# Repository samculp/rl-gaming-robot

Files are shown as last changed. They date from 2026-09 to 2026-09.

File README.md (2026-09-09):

# RL Gaming Robot

The RL Gaming Robot is a senior design project focused on developing a Reinforcement Learning system that learns to play games through repeated attempts and applies its learned behavior to a game to ultimately improve its score.

The current target game is Tetris. The long-term goal is for the RL agent to make gameplay decisions and output controller commands that are translated into physical actions pressed on a controller by a robotic system.

This repository contains the software and hardware elements used to create the project.

## Repository Structure

```text
RL-Gaming-Robot/

├── hardware/
│   ├── experiments/
│   │   ├── actuator_pulse/
│   │   └── cad_files/
│   └── production/
│
├── software/
│   ├── requirements/
│   ├── environment/
│   ├── agent/
│   └── test_cases/
│
└── README.md
```

## Hardware

The `hardware` directory contains the mechanical and electronic development files for the RL Gaming Robot.

This includes:

* Actuator experiments and testing
* CAD models and mechanical designs
* Controller mounting and interaction components
* Production hardware designs
* Hardware documentation and validation

See the [hardware README](hardware/README.md) for additional information.

## Software

The `software` directory contains the software required to develop and operate the RL system.

This includes:

* Python environment and dependency requirements
* Game environment code
* Reinforcement Learning agent code
* Software test cases

The software is responsible for interacting with the game environment, training and executing the RL agent, and producing controller actions for the hardware system.

See the [software README](software/README.md) for additional information.

## System Overview

The intended system operates as a feedback loop:

```text
┌─────────────────┐
│    NES Tetris   │
└────────┬────────┘
         │
         │ Game State
         ▼
┌─────────────────┐
│ Game Environment│
└────────┬────────┘
         │
         │ State
         ▼
┌─────────────────┐
│    RL Agent     │
└────────┬────────┘
         │
         │ Controller Action
         ▼
┌─────────────────┐
│ Robot Controller│
└────────┬────────┘
         │
         │ Physical Command
         ▼
┌─────────────────┐
│  Robotic System  │
└────────┬────────┘
         │
         │ Button Press
         ▼
┌─────────────────┐
│  NES Controller │
└────────┬────────┘
         │
         └──────────────► NES Tetris
```

The game produces a new state after each action, allowing the RL agent to continually evaluate the game and select its next action.

## Testing

Testing is an integral part of the project and is performed throughout both software and hardware development.

Software testing focuses on:

* Game-state processing
* RL agent behavior
* Action generation
* Software component integration
* Model performance and repeatability

Hardware testing focuses on:

* Actuator performance
* Button press accuracy
* Timing and reliability
* Mechanical positioning
* Hardware/software integration

Test cases are maintained within the appropriate software and hardware directories.

## Development Philosophy

The project is organized around **experimentation, validation, and integration**.

Development follows these general principles:

1. **Experiment** — Develop and test individual concepts and components.
2. **Validate** — Verify that components meet their intended requirements.
3. **Integrate** — Combine validated software and hardware components.
4. **Test** — Evaluate the complete system and identify integration issues.
5. **Iterate** — Use test results to improve the system.

Experimental implementations should be validated before being incorporated into the production system.

## Project Goals

The primary goals of the RL Gaming Robot project are to:

* Develop an RL agent capable of improving its gameplay through repeated attempts.
* Create a software environment for training and evaluating the agent.
* Develop a robotic system capable of physically interacting with a gaming controller.
* Establish reliable communication between the software and hardware systems.
* Test the performance and reliability of the complete system.
* Demonstrate the transfer of learned behavior from the software environment to physical gameplay.

## Current Development Status

The project is being developed incrementally, beginning with the software RL environment and agent before progressing toward full hardware integration.

Major development stages include:

1. Software environment development
2. RL agent development and training
3. Software testing and performance evaluation
4. Hardware development and validation
5. Software/hardware integration
6. Full-system testing
7. Final NES Tetris demonstration

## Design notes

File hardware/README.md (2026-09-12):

# Hardware

Hardware design, firmware, schematics, experiments, and documentation for the RL gaming robot.

## Directories

* [`electronics/`](electronics/) — Electrical system documentation, PCB design, power budget, and wiring diagrams.
* [`mechanical/`](mechanical/) — Mechanical design documentation and CAD files.
* [`firmware/`](firmware/) — Arduino firmware for the hardware control system.
* [`experiments/`](experiments/) — Hardware and controller experiments used during development.
* [`photos/`](photos/) — Miscellaneous ardware photos.

## System Overview

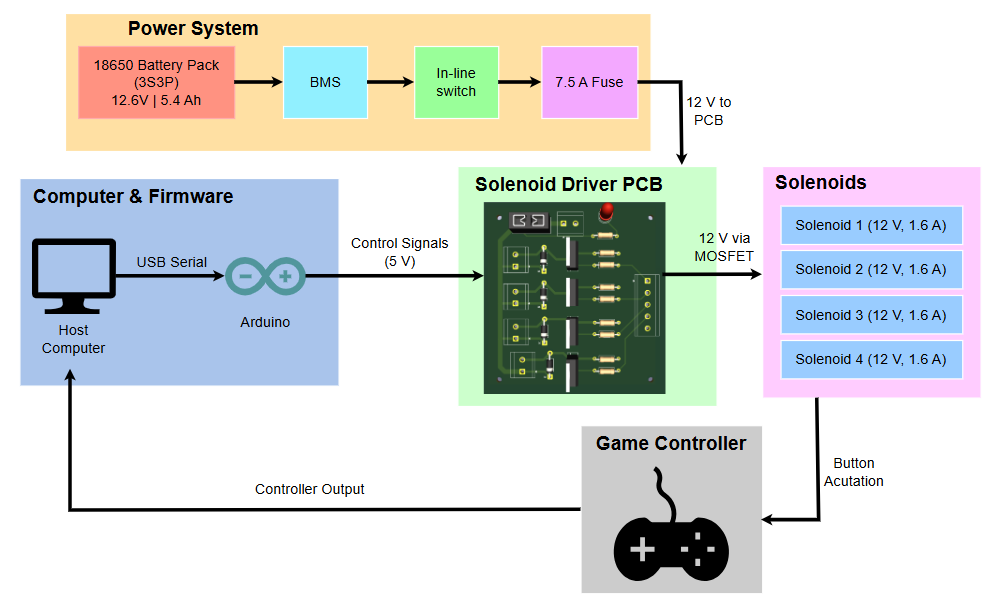
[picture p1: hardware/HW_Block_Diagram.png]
Hardware Block Diagram


For detailed electrical architecture and subsystem documentation, see [`electronics/`](electronics/).

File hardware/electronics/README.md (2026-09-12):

# Electronics

The electronics system controls and powers the solenoid actuators used to physically operate the game controller.

## Subsystems

- [PCB](pcb/README.md) — Solenoid driver PCB design and fabrication files
- [Power](power/power_budget.md) — Battery and system power requirements
- [Wiring](wiring/) — Electrical wiring and connections (visual)

## Signal Path

Arduino → MOSFET driver → Solenoids

## Power Path

Battery → BMS → Power switch → Fuse  → Solenoid driver PCB → Solenoids

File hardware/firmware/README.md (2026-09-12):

# Firmware

Arduino firmware for controlling the solenoid driver PCB and translating commands received over USB into physical controller inputs.

## Planned Contents

- Arduino source code
- Pin assignments
- Serial communication protocol
- Solenoid control logic

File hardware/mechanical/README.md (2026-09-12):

# Mechanical

Mechanical components for mounting and positioning the solenoid actuators over the game controller.

## CAD Files

- `Actuator Plate.f3d` — Mounting plate for the solenoid actuators; actuators are friction fit into sleeves
- `SNES Cradle.f3d` — Mount for the game controller
- `Solenoid Sleeve.f3d` — Test sleeve for positioning and guiding the solenoid
- `snes_overlay.jpg` — Controller reference image used during CAD design

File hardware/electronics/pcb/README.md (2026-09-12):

# Solenoid Driver PCB

Custom PCB for interfacing the Arduino with four 12 V solenoid actuators.

## Components

| Component | Quantity | Purpose |
| --- | ---: | --- |
| IRLZ44N N-channel MOSFET | 4 | Electrically switches each solenoid on and off using the Arduino control signal. |
| 1N4004 diode | 4 | Provides flyback protection by suppressing the voltage spike generated when a solenoid is switched off. |
| 220 Ω gate resistor | 4 | Limits current into each MOSFET gate and provides controlled gate drive. |
| 10 kΩ pull-down resistor | 4 | Pulls the gate of each MOSFET down to GND when it is not being driven HIGH by the Arduino. |
| Green LED | 1 | Indicates that the PCB is receiving power. |
| 1 kΩ resistor | 1 | Limits current through the power indicator LED. |
| 2-position screw terminal | 1 | Provides the 12 V power input connection. |
| 2-position screw terminal | 4 | Provides connections for the four solenoids and power/ground distribution. |
| 5-position screw terminal | 1 | Provides the control signal and ground connections between the Arduino and PCB. |
| 7.5 A blade fuse | 1 | Protects the PCB and solenoid power circuit from excessive current. |
| Fuse holder | 1 | Holds the 7.5 A blade fuse in the solenoid power path. |
| M2 mounting holes | 4 | Secure the PCB to the mechanical assembly. |

## Files

* `solenoid_driver.kicad_sch` — Electrical schematic.
* `solenoid_driver.kicad_pcb` — PCB layout.
* `solenoid_driver.kicad_pro` — KiCad project file.

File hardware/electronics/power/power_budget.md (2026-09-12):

# Power Budget

## Battery Pack

The battery pack consists of nine 18650 lithium-ion cells configured as 3S3P. Each cell has an approximate capacity of 1.8 Ah and a nominal voltage of 3.6-3.7 (4.2 V fully charged).

- Configuration: 3S3P
- Cells: 9 × 18650
- Nominal voltage: 10.8-11.1 V
- Maximum voltage: 12.6 V
- Capacity: 5.4 Ah
- Approximate energy: 58-60 Wh

## Power Path

Battery → BMS → In-line switch → XT60 → 7.5 A fuse → PCB → Solenoids

The Arduino is powered separately through USB.

## Solenoid Load

Each solenoid is rated for 12 V and draws a maximum of 1.6 A.

| Load | Voltage | Max Current | Quantity | Total Max Current |
|---|---:|---:|---:|---:|
| Solenoid | 12 V | 1.6 A | 4 | 6.4 A |

The maximum combined solenoid current is approximately 6.4 A when all four solenoids are activated simultaneously.

## Protection

- Fuse: 7.5 A blade fuse
- Maximum solenoid load: 6.4 A
- Fuse margin: 1.1 A

The BMS (battery management system) provides:
- Overcharge protection
- Over-discharge protection
- Overcurrent and short-circuit protection
- Cell balancing

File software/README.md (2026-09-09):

# RL Gaming Robot Software
This directory contains the software development files for the RL Gaming Robot project. It includes requirements, environment python codes, agent python codes, and test case codes.

## Directory Structure
```text

software/
├── requirements/
├── environment/
├── agent/
└── test_cases/

```

## Requirements
The requirements for the software side of the project must include a few main features
* Python 3.x - Main programming language
    * Gymnasium Library - Reinforcement Learning environment
    * PyTorch - Used to develop and train the RL model 
    * PyToch Vision - Addon to PuTorch to handle video and images
    * PyInput - Used to listen to inputs while not having an open window like PyGame
* Git - Version control and repository management

## Environment
This project plans to use the gymnasium library to create an environment for the agent

## Agent
The agent is also provided via Gymnasium

## Test Cases
Test cases are recorded and graphed/stored, showing that the RL model is improving.

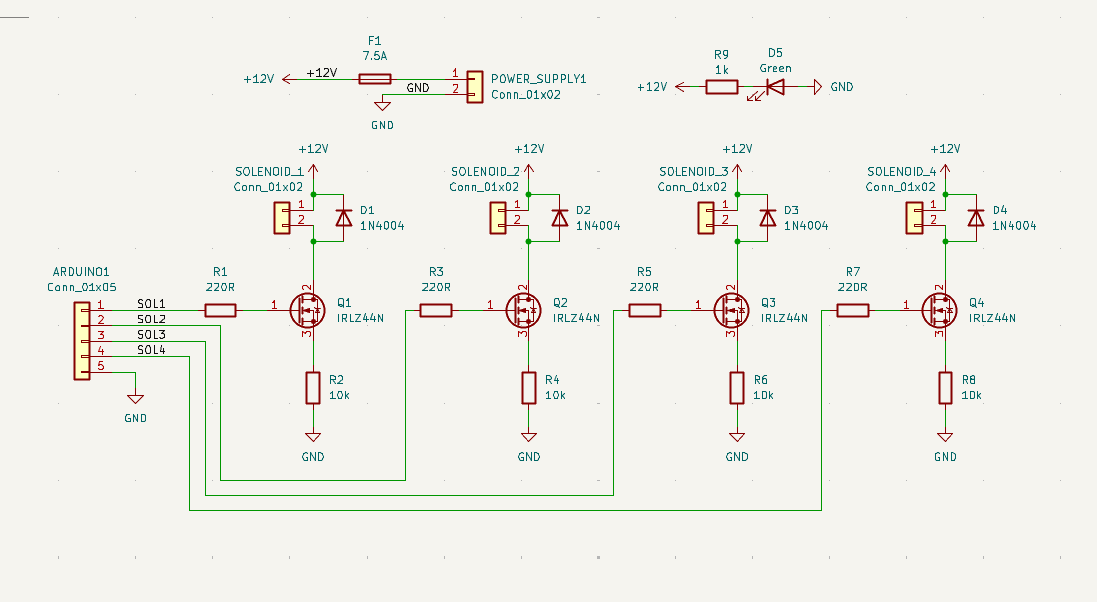
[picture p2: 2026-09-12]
hardware/electronics/wiring/schematic_diagram.png

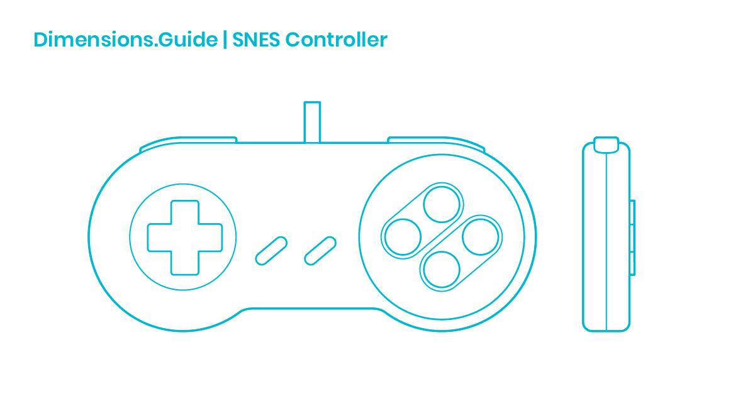
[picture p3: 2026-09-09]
hardware/mechanical/cad/snes_overlay.jpg

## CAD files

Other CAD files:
hardware/mechanical/cad/Actuator Plate.f3d
hardware/mechanical/cad/SNES Cradle.f3d
hardware/mechanical/cad/Solenoid Sleeve.f3d

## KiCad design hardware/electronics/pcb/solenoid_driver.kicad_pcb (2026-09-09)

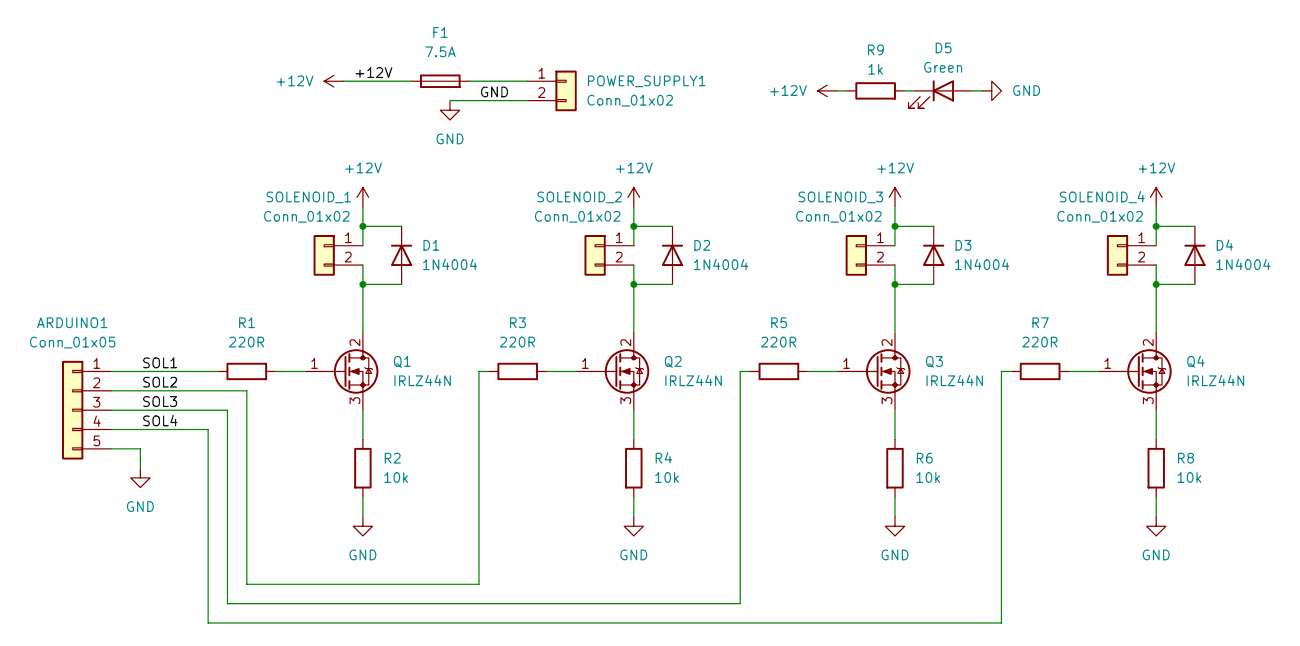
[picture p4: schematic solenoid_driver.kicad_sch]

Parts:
ARDUINO1: Conn_01x05; TerminalBlock_CUI_TB007-508-05_1x05_P5.08mm_Horizontal
D1, D2, D3, D4: 1N4004; D_DO-41_SOD81_P10.16mm_Horizontal
D5: Green; LED_D5.0mm
F1: 7.5A; Fuseholder_Blade_Mini_Keystone_3568
POWER_SUPPLY1: Conn_01x02; TerminalBlock_CUI_TB007-508-02_1x02_P5.08mm_Horizontal
Q1, Q2, Q3, Q4: IRLZ44N; TO-220-3_Vertical
R1, R3, R5, R7: 220R; R_Axial_DIN0207_L6.3mm_D2.5mm_P10.16mm_Horizontal
R2, R4, R6, R8: 10k; R_Axial_DIN0207_L6.3mm_D2.5mm_P10.16mm_Horizontal
R9: 1k; R_Axial_DIN0207_L6.3mm_D2.5mm_P10.16mm_Horizontal
SOLENOID_1, SOLENOID_2, SOLENOID_3, SOLENOID_4: Conn_01x02; TerminalBlock_CUI_TB007-508-02_1x02_P5.08mm_Horizontal

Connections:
+12V: D1.1 (K), D2.1 (K), D3.1 (K), D4.1 (K), F1.1, R9.1, SOLENOID_1.1, SOLENOID_2.1, SOLENOID_3.1, SOLENOID_4.1
/SOL1: ARDUINO1.1, R1.1
/SOL2: ARDUINO1.2, R3.1
/SOL3: ARDUINO1.3, R5.1
/SOL4: ARDUINO1.4, R7.1
GND: ARDUINO1.5, D5.2 (A), POWER_SUPPLY1.2, R2.2, R4.2, R6.2, R8.2
unnamed: D1.2 (A), Q1.2 (D), SOLENOID_1.2
unnamed: D2.2 (A), Q2.2 (D), SOLENOID_2.2
unnamed: D3.2 (A), Q3.2 (D), SOLENOID_3.2
unnamed: D4.2 (A), Q4.2 (D), SOLENOID_4.2
unnamed: D5.1 (K), R9.2
unnamed: F1.2, POWER_SUPPLY1.1
unnamed: Q1.1 (G), R1.2
unnamed: Q1.3 (S), R2.1
unnamed: Q2.1 (G), R3.2
unnamed: Q2.3 (S), R4.1
unnamed: Q3.1 (G), R5.2
unnamed: Q3.3 (S), R6.1
unnamed: Q4.1 (G), R7.2
unnamed: Q4.3 (S), R8.1

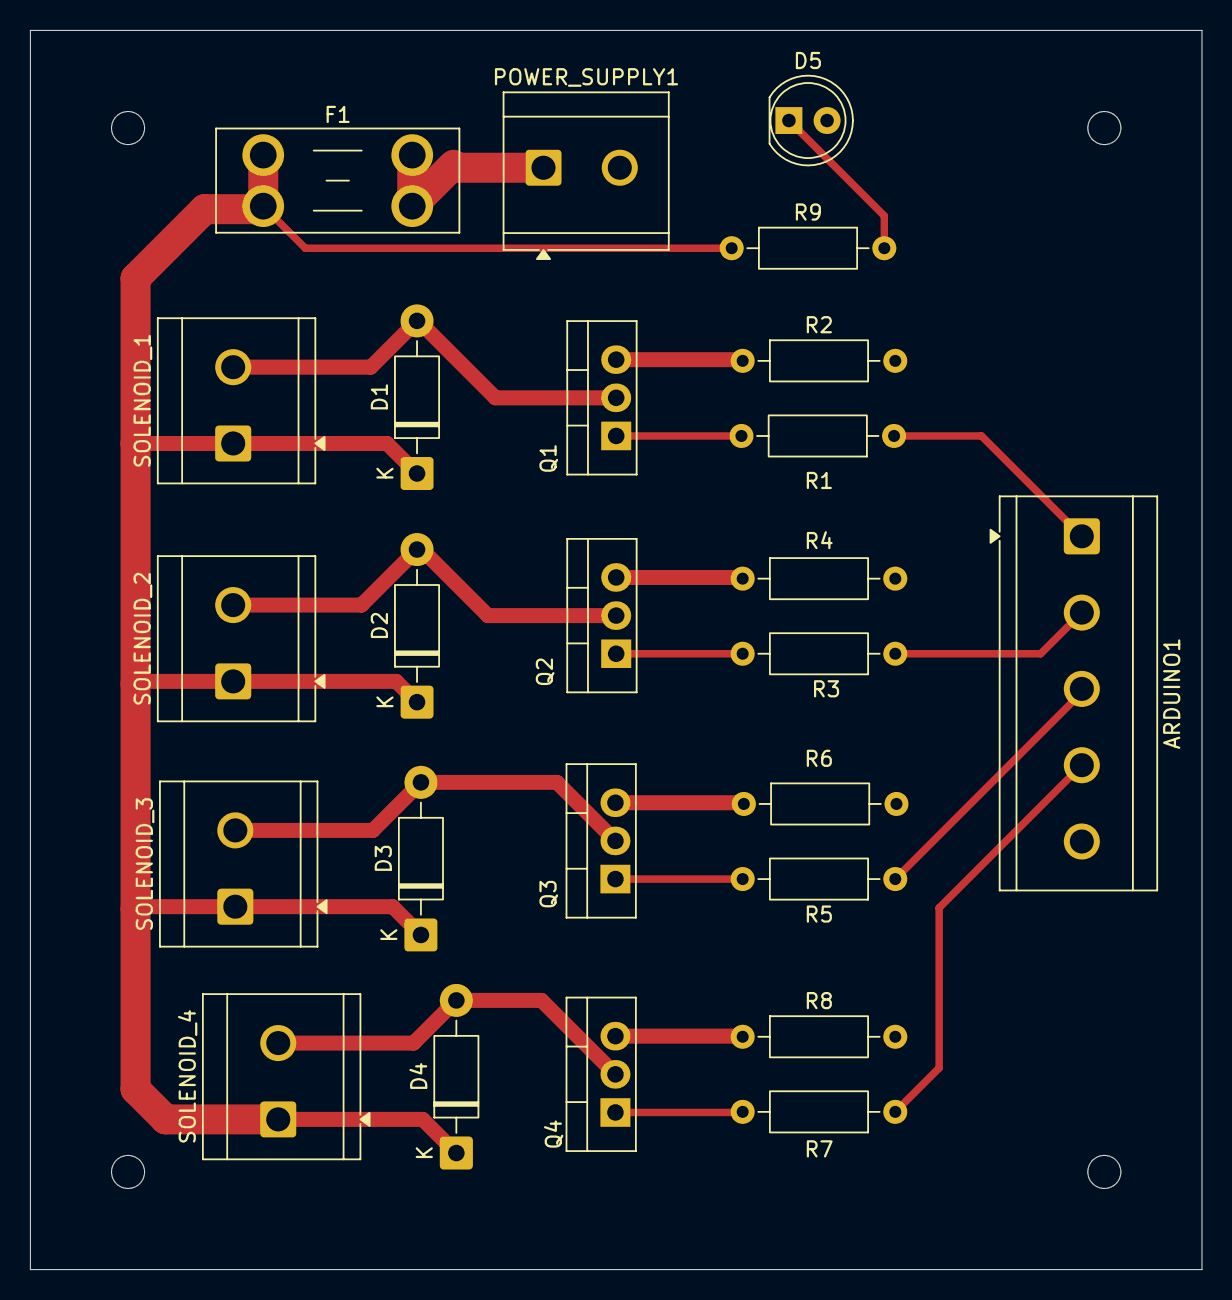
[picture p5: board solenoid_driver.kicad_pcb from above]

Board: 2 copper layers, 78.0 x 82.5 mm, 25 parts (0 on the bottom side), 20 nets.

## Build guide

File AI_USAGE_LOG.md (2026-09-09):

# AI Usage & Verification Log

**Project Name:** RL Gaming Robot

---

## Overview & AI Usage Statement

### Overview & AI Usage Statement

AI tools were used throughout the project as a supplemental development resource for brainstorming, troubleshooting, and improving implementation approaches. AI-generated code and recommendations were reviewed, tested, and modified by the project team before being incorporated into the project. The team remains responsible for understanding and verifying all implemented solutions. AI was not treated as a replacement for independent research, engineering judgment, or testing.

### Responsible AI Usage

AI was used responsibly by treating its output as a starting point rather than an authoritative source. Generated code was reviewed for correctness, tested in the project environment, and modified when necessary. Project decisions and final implementations were verified by the team, and AI assistance was documented in this log to maintain transparency and accountability.

---

## Entry 1: Prototype 1 - SNES USB Controller Input Mapping Experiment

* **Date:** August 31, 2026  
* **Tool Used:** ChatGPT  
* **Associated Git Issue:** Test SNES USB controller input mapping  
* **Associated Feature Branch:** `controller-input-test`  

### Exact Prompt Submitted:

> "quick python script for testing input on this snes usb controller i just got from walmart"

### AI Output Summary & Code Generated

AI generated a Python script using the `pygame` library to:

* Detect connected USB controllers.
* Display the controller name.
* Display the number of buttons, axes, and hats detected.
* Print button press events.
* Print button release events.
* Print joystick axis movement values.
* Print D-pad or hat movement values when applicable.

The generated experiment allowed the physical SNES USB controller to be tested interactively.

### Human Testing, Verification & Results

The controller was manually tested using the generated Python experiment. The following input mappings were observed and recorded:

#### Button Mapping

| SNES Button | Input Mapping |
|---|---:|
| X | Button 0 |
| A | Button 1 |
| B | Button 2 |
| Y | Button 3 |
| Select | Button 8 |
| Start | Button 9 |

#### D-Pad Mapping

The controller D-pad was detected as two joystick axes rather than individual buttons or a joystick hat.

| Direction | Axis | Value When Pressed |
|---|---:|---:|
| Left | Axis 0 | -1 |
| Right | Axis 0 | 1 |
| Up | Axis 1 | -1 |
| Down | Axis 1 | 1 |
| Released | Axis 0 / Axis 1 | Approximately -0.01 |

### Human Review & Modifications Identified

Testing identified that the D-pad does not return exactly `0` when released. Instead, the controller reports a value of approximately `-0.01`.

Based on this result, future controller input handling should implement a dead zone rather than checking for an exact axis value of zero.

Example dead zone approach:

```python
DEADZONE = 0.5

if axis_0 < -DEADZONE:
    print("LEFT")
elif axis_0 > DEADZONE:
    print("RIGHT")

if axis_1 < -DEADZONE:
    print("UP")
elif axis_1 > DEADZONE:
    print("DOWN")
```

---

## Entry 2: CI/CD Infrastructure - Pytest Unit Test Setup

* **Date:** September 8, 2026  
* **Tool Used:** ChatGPT  
* **Associated Git Issue:** CI/CD Infrastructure & Test Logs  
* **Associated Feature Branch:** `chore/cicd-implementation`  

### Exact Prompts Submitted:

> "whats best practice for virtual environments when i have a bunch of python tests like this"

> "Record pygame as a project dependency"

> "what directory should tests go under"

> "next"

> "okay next"

> "run tests failed. said no module named pytest but install dependecies worked and pytest was included in that"

> "add this conversation about setting up pytest to this log"

### AI Output Summary & Code Generated

ChatGPT provided guidance for establishing a Python unit-testing structure suitable for CI/CD. The guidance included:

* Moving the Python virtual environment from the individual hardware experiment directory to the repository root.
* Using one project-level virtual environment rather than separate virtual environments for individual test files.
* Adding `pygame` and `pytest` as project dependencies in `requirements.txt`.
* Keeping the virtual environment out of source control through `.gitignore`.
* Creating a top-level `tests/` directory for automated unit tests.
* Renaming the hardware controller experiment so pytest would not automatically discover it as a test module.
* Separating executable controller code from importable code by placing the controller program inside a `main()` function and using an `if __name__ == "__main__":` guard.
* Creating a unit-testable `get_button_action()` function and a corresponding pytest test.
* Configuring GitHub Actions to install dependencies and execute tests on pull requests.

### Human Testing, Verification & Results

The initial pytest execution failed because the hardware controller experiment was automatically collected as a test module and attempted to access a physical controller.

After restructuring the controller experiment, pytest was able to collect and execute the unit test without requiring physical hardware.

The final local test execution successfully reported:

```text
1 passed
```

The GitHub Actions workflow was then configured to install dependencies from `requirements.txt` and execute:

```text
python -m pytest
```

An initial CI failure was traced to an empty `requirements.txt`. After adding the required dependencies:

```text
pygame
pytest
```

the GitHub Actions test job successfully passed.

### Human Review & Modifications Identified

Human review determined that the original controller experiment was an interactive hardware test rather than a unit-testable module. The code was therefore modified so importing the module does not immediately initialize the controller or terminate when no controller is connected.

The CI workflow was also verified through a pull request, confirming that the automated pytest execution can run successfully in GitHub Actions without physical controller hardware.

---

## Entry 3: CI/CD Infrastructure - Ruff Linting

* **Date:** September 9, 2026  
* **Tool Used:** ChatGPT  
* **Associated Git Issue:** CI/CD Infrastructure & Test Logs  
* **Associated Feature Branch:** `chore/cicd-implementation`

### Exact Prompts Submitted:

> "lets continue with linting"

> "all checks passed"

> "it needs to be included in the yaml right?"

### AI Output Summary & Code Generated

ChatGPT provided guidance for adding Ruff as the project's Python linting tool. The guidance included:

* Adding `ruff` to `requirements.txt` alongside `pygame` and `pytest`.
* Installing Ruff in the project virtual environment.
* Running `python -m ruff check .` locally to identify linting issues.
* Reviewing Ruff's reported issues rather than automatically applying fixes.
* Adding a GitHub Actions workflow step to execute `python -m ruff check .` so linting is automatically performed in CI on pull requests.

### Human Testing, Verification & Results

The initial local Ruff check identified four issues: two import-formatting issues and two uses of `quit()` where Ruff recommended `sys.exit()`.

The controller input module was modified to import `sys` and replace both `quit()` calls with `sys.exit()`.

Ruff was run again with:

```text
python -m ruff check .
```

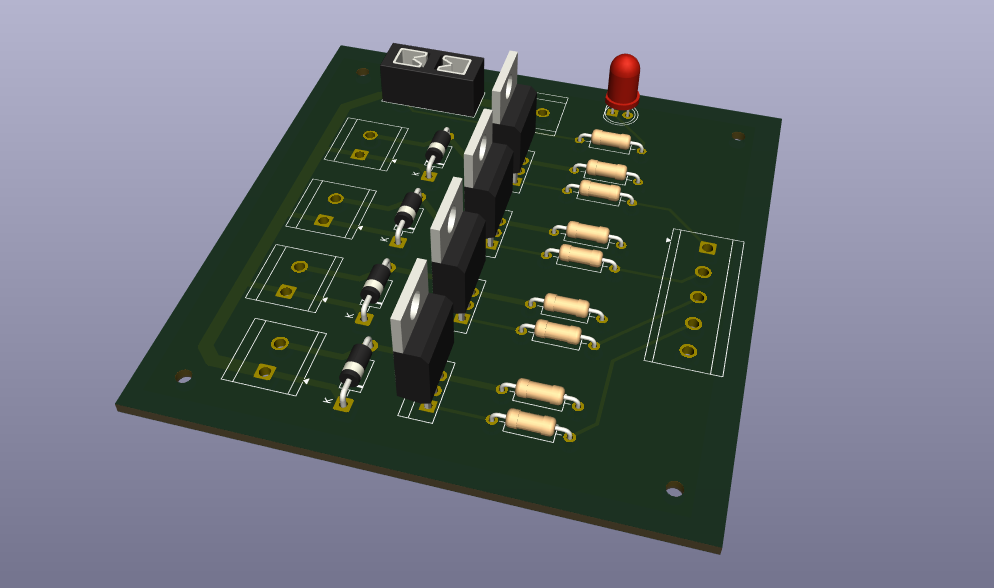
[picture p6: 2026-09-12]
hardware/electronics/wiring/pcb_3d_view.png

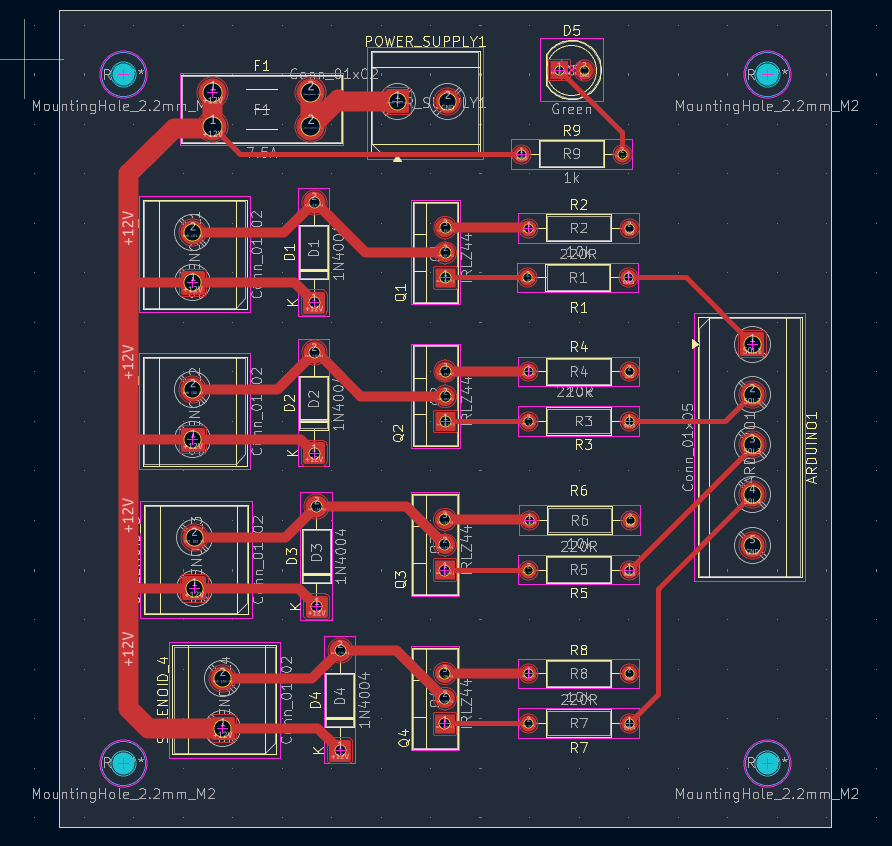
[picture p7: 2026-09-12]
hardware/electronics/wiring/pcb_diagram.png

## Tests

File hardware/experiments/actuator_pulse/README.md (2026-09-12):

## Experiment: Actuator Pulse

The purpose of this experiment is to verify that the laptop can send signals to the arduino and in turn activate the solenoids. It also serves the purpose of verifying that the solenoids are strong enough to press buttons on the controller.

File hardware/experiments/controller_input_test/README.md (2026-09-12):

## Experiment: Controller Input Mapping

The purpose of this experiment is to record what python sees when a button is pressed on the USB SNES controller.

## Results

Controller input testing was completed using the Python `pygame` experiment.

### Button Mapping

| SNES Button | Input |
|---|---:|
| X | Button 0 |
| A | Button 1 |
| B | Button 2 |
| Y | Button 3 |
| Select | Button 8 |
| Start | Button 9 |

### D-Pad Mapping

The D-pad is detected as two joystick axes rather than individual buttons or a hat.

| Direction | Axis | Value When Pressed |
|---|---:|---:|
| Left | Axis 0 | -1 |
| Right | Axis 0 | 1 |
| Up | Axis 1 | -1 |
| Down | Axis 1 | 1 |
| Released | Axis 0/1 | -0.01 |

### Notes

- Horizontal D-pad input is reported on Axis 0.
- Vertical D-pad input is reported on Axis 1.
- D-pad values are `-1` or `1` when pressed.
- When released, the controller reports approximately `-0.01` instead of exactly `0`, so input handling should use a dead zone rather than checking for an exact value of zero.

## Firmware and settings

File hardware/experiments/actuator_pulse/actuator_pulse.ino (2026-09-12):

// testing one unit of the robot
// continuously pulses to trigger the solenoid
// pin 2 is connected to the gate of the MOSFET

const int solenoidPin = 2;

void setup() {
  Serial.begin(115200);
  Serial.println("Enter 1 to pulse:");
  pinMode(solenoidPin, OUTPUT);
}

void loop() {
  if (Serial.available() > 0) {
    char command = Serial.read();
    
    if (command == '1') {
      pulse();
    }
  }
}

void pulse() {
  Serial.println("Pulsing...");
  digitalWrite(solenoidPin, HIGH);
  delay(100);
  digitalWrite(solenoidPin, LOW);
}

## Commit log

2026-04-10 initial servo plunger test
2026-04-15 servo test and cradle STL file
    [NES Cradle.stl]
2026-08-28 pulse test for one unit of the solenoids
    [robot_plate.stl, test-sleeve.stl]
2026-09-02 docs: initialized AI usage log (#5)
    [SNES Cradle.f3d]
2026-09-03 feat: design schematics for solenoid driver PCB (#7)
    [NES Cradle.stl, SNES_cradle.stl, solenoid_driver.kicad_pcb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]
2026-09-03 feat: in-line fuse on PCB (#7)
    [solenoid_driver.kicad_pcb, solenoid_driver.kicad_sch]
2026-09-12 docs: created hardware_architecture documentation
    [Actuator Plate.f3d, SNES Cradle.f3d, SNES_cradle.stl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]
2026-09-12 docs: electronics documentation
    [solenoid_driver.kicad_pcb, solenoid_driver.kicad_sch]
2026-09-12 docs: added firmware directory and documentation
    [Actuator Plate.f3d, SNES Cradle.f3d, Solenoid Sleeve.f3d]
